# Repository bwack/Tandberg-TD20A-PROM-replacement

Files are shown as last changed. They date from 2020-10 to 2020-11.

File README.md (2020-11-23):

# Tandberg-TD20A-PROM-replacement

A few attempts to solve the problematic, hard to get, hard to program PROM in the Tandberg TD20A Reel to Reel Tape Recorder PROM (U3).

Assembler program written by BWACK 2020.
ROM dumps by Knut Baardsen. RIP. You will always be missed.

Cut pin15 for 15 IPS, ground pin15 for 7.5 IPS

This project was successful. A chip is now installed in a real product that needed repair.
You can see all about it in these two videos:

## Programming

I used the TL866. Load the hex file, set the correct fuses (see the .fuses file).
For myself I have installed minipro on ubuntu, and this is what I run:

minipro -p ATTINY2313 -c code -f ihex -w tda20_prom_attiny2313.hex && \
minipro -p ATTINY2313 -c config -w tda20_prom_attiny2313.fuses

## YouTube videos:

videothumb (http://www.youtube.com/watch?v=v1Pzl6MGUO8 "Creating a PROM replacement using ATTiny2313 and the AVRA Macro Assembler - Tandberg TD20A PROM IC")

TD20 update video showing the chip in action:

videothumb (http://www.youtube.com/watch?v=RYnCFkmXLnY "Tandberg TD 20A update and ATtiny1606 breakout boards (soldering video)")

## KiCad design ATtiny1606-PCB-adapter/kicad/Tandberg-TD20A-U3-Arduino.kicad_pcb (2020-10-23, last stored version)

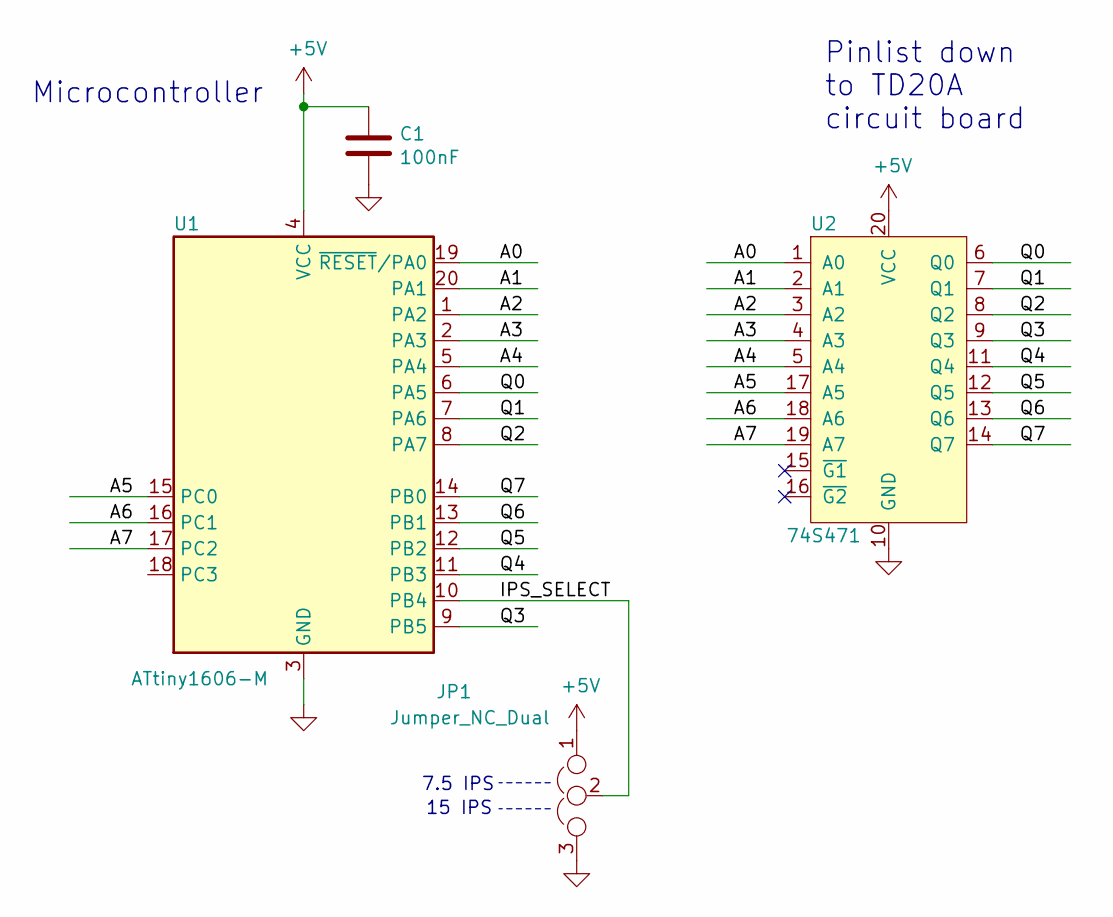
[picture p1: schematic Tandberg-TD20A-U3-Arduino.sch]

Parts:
C1: 100nF; C_0603_1608Metric_Pad1.05x0.95mm_HandSolder
JP1: Jumper_NC_Dual; SolderJumper-3_P1.3mm_Open_RoundedPad1.0x1.5mm_NumberLabels
U1: ATtiny1606-M; VQFN-20-1EP_3x3mm_P0.4mm_EP1.7x1.7mm
U2: 74S471; DIP-20_W7.62mm

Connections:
+5V: C1.1, JP1.1, U1.4 (VCC), U2.20 (VCC)
/A0: U1.19 (~RESET~/PA0), U2.1 (A0)
/A1: U1.20 (PA1), U2.2 (A1)
/A2: U1.1 (PA2), U2.3 (A2)
/A3: U1.2 (PA3), U2.4 (A3)
/A4: U1.5 (PA4), U2.5 (A4)
/A5: U1.15 (PC0), U2.17 (A5)
/A6: U1.16 (PC1), U2.18 (A6)
/A7: U1.17 (PC2), U2.19 (A7)
/IPS_SELECT: JP1.2, U1.10 (PB4)
/Q0: U1.6 (PA5), U2.6 (Q0)
/Q1: U1.7 (PA6), U2.7 (Q1)
/Q2: U1.8 (PA7), U2.8 (Q2)
/Q3: U1.9 (PB5), U2.9 (Q3)
/Q4: U1.11 (PB3), U2.11 (Q4)
/Q5: U1.12 (PB2), U2.12 (Q5)
/Q6: U1.13 (PB1), U2.13 (Q6)
/Q7: U1.14 (PB0), U2.14 (Q7)
GND: C1.2, JP1.3, U1.3 (GND), U1.21 (GND), U2.10 (GND)

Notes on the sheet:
7.5 IPS
15 IPS
Microcontroller
Pinlist down to TD20A circuit board

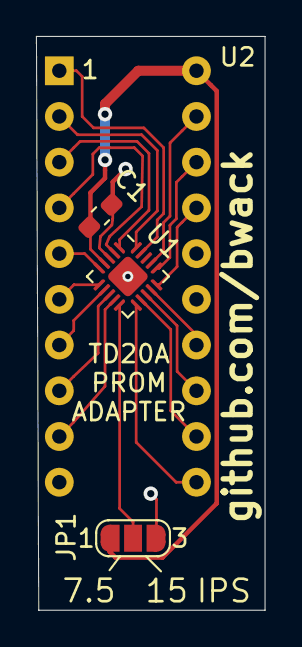
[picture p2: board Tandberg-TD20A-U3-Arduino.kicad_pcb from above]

Board: 2 copper layers, 12.7 x 31.9 mm, 4 parts (0 on the bottom side), 19 nets.

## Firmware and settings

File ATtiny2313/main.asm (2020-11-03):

; Tandberg TD20A Reel to Reel Tape Recorder PROM (U3) drop-in replacement.
; Written by BWACK 2020
; ROM dumps by Knut Baardsen. RIP. You will always be missed.
;
; Cut pin15 for 15 IPS, ground pin15 for 7.5 IPS

.nolist
.ifdef ATTINY2313
.include "tn2313def.inc"
.else
.include "tn2313Adef.inc"
.endif
.list

; inputs
.equ A0		= PA2
.equ A1		= PD0
.equ A2		= PD1
.equ A3		= PA1
.equ A4		= PA0
.equ A5		= PB5
.equ A6		= PB6
.equ A7		= PB7

; outputs
.equ Q0		= PD2
.equ Q1		= PD3
.equ Q2		= PD4
.equ Q3		= PD5
.equ Q4		= PD6
.equ Q5		= PB0
.equ Q6		= PB1
.equ Q7		= PB2

.equ G1_N	= PB3
.equ G2_N	= PB4

.def tmp	= r16
.def tmp2	= r17
.def output     = r18
.def input      = r19

.def loopCt	= r20		; delay loop count
.def loopCt2	= r21		; adc loop count
.def iLoopRl	= r24		; inner loop register low
.def iLoopRh	= r25		; inner loop register high

.dseg
.org	SRAM_START
sample:
.byte	2

.cseg
.org	0x0000		; reset vector
	rjmp setup
.org	WDTaddr		; Watchdog time-out vector
; 	rjmp WDT_isr

.org 0x0013

prom_data_7_5_ips:
.include "prom_data_td20_7.5ips.inc"

prom_data_15_ips:
.include "prom_data_td20_15ips.inc"

setup:
 	ldi	tmp, low(RAMEND)	; init stack pointer
 	out	SPL, tmp
 	; ldi	tmp, high(RAMEND)
 	; out	SPH, tmp

	; inputs
	cbi	DDRA, PA2
	cbi	DDRD, PD0
	cbi	DDRD, PD1
	cbi	DDRA, PA1
	cbi	DDRA, PA0
	cbi	DDRB, PB5
	cbi	DDRB, PB6
	cbi	DDRB, PB7
	cbi	DDRB, G1_N
	cbi	DDRB, G2_N
	sbi	PORTB, G1_N ; pull_up
	sbi	PORTB, G2_N ; pull_up

	; outputs;
	sbi	DDRD, PD2
	sbi	DDRD, PD3
	sbi	DDRD, PD4
	sbi	DDRD, PD5
	sbi	DDRD, PD6
	sbi	DDRB, PB0
	sbi	DDRB, PB1
	sbi	DDRB, PB2


loop:
	; read inputs

	; A4   : PA0
	; A3   : PA1
	; A0   : PA2
	; A1-A2: PD0-PD1
	; A5-A7: PB5-PB7

	clr	input
	in	tmp, PINA
	sbrc	tmp, A4
	ori	input, 0b00010000
	sbrc	tmp, A3
	ori	input, 0b00001000
	sbrc	tmp, A0
	ori	input, 0b00000001

	in	tmp, PINB
	bst	tmp, G1_N
	andi	tmp, 0b11100000
	or	input, tmp

	in	tmp, PIND
	rol	tmp
	andi	tmp, 0b00000110
	or	input, tmp

	; code memory lookup

	brts	td20_prom_15_ips_lookup ; G1_N clear -> 15 IPS
td20_prom_7_5_ips_lookup:
	ldi	ZL, LOW(prom_data_7_5_ips*2)
 	ldi	ZH, HIGH(prom_data_7_5_ips*2)
	rjmp	add_table_offset
td20_prom_15_ips_lookup:
	ldi	ZL, LOW(prom_data_15_ips*2)
 	ldi	ZH, HIGH(prom_data_15_ips*2)
add_table_offset:
 	clr	tmp
 	clc
 	add	ZL, input	; table offset
 	adc	ZH, tmp
 	lpm	output, Z	; lookup

	; set outputs

	; Q0-Q4 = PD2..PD6
	; Q5-Q7 = PB0..PB2

	mov	tmp, output
	andi	tmp, 0x1f
	lsl	tmp	
	lsl	tmp	
	out	PORTD, tmp

	mov	tmp, output
	andi	tmp, 0xe0
	lsr	tmp
	swap	tmp
	ori	tmp, (1<<G1_N)|(1<<G2_N) ; maintain pull-ups
	out	PORTB, tmp

 	; ldi	iloopRl, LOW(100)
 	; ldi	iloopRh, HIGH(100)
 	; rcall	delay_ms
	; ldi	tmp, 1
	; add	output, tmp

	rjmp loop

delay_ms:
.equ delayconst = 80
.equ delayconst2 = 2
	push 	tmp
	push 	tmp2
	ldi	tmp, delayconst
	ldi	tmp2, delayconst2
_delay_ms:
	dec	tmp
	brne	_delay_ms
	ldi	tmp, delayconst
	dec	tmp2
	brne	_delay_ms
	ldi	tmp2, delayconst2

 	sbiw	iloopRl,1
	brne	_delay_ms
	pop	tmp2
	pop	tmp
	ret

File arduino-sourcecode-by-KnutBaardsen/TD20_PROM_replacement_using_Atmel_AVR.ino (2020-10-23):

// Replacement for the TD20A PROM. 
// Circuit in use is an Atmel AVR Mega328, but can be adapted for any MCU with 16 free I/O lines.
// Written by Knut Baardsen September 2016 (knut@baso.no)
// Can be freely used and changed, but not for commercial usage!

byte data_in;
byte data_out;

// Data for 7.5 IPS (PINK color marking)
byte td20_75[256] = {
  0b10000110,0b10000110,0b10100110,0b11000101,0b10100110,0b10100010,0b10100001,0b11100001,
  0b10101110,0b10101010,0b10101001,0b11101001,0b10110110,0b10110010,0b10110001,0b11110001,
  0b11100101,0b10100101,0b11100110,0b10101101,0b10100111,0b10100001,0b10100001,0b10100001,
  0b10100111,0b10100001,0b10100001,0b10100001,0b10111111,0b10100101,0b10100101,0b10101101,
  0b10011110,0b11011111,0b10011110,0b11000101,0b10100110,0b11100011,0b10100001,0b11100001,
  0b10101110,0b11101011,0b10101001,0b11101001,0b10110110,0b11110011,0b10110001,0b11110001,
  0b11101101,0b10101101,0b01101111,0b10101110,0b10100111,0b10100001,0b10100001,0b10100001,
  0b10100111,0b10100001,0b10100001,0b10100001,0b11100110,0b10100101,0b11100110,0b10101101,
  0b10000110,0b10000110,0b10100110,0b11000101,0b10100110,0b10100010,0b10100001,0b11100001,
  0b10101110,0b10101010,0b10101001,0b11101001,0b10110110,0b10110010,0b10110001,0b11110001,
  0b11100101,0b10100101,0b11100110,0b10101101,0b10100111,0b10100001,0b10100001,0b10100001,
  0b10100111,0b10100001,0b10100001,0b10100001,0b10111111,0b10100101,0b10100101,0b10101101,
  0b10011110,0b11011111,0b10011110,0b11000101,0b10100110,0b11100011,0b10100001,0b11100001,
  0b10101110,0b11101011,0b10101001,0b11101001,0b10110110,0b11110011,0b10110001,0b11110001,
  0b11101101,0b10101101,0b01101111,0b10101110,0b10100111,0b10100001,0b10100001,0b10100001,
  0b10100111,0b10100001,0b10100001,0b10100001,0b11100110,0b10100101,0b11100110,0b10101101,
  0b10011110,0b10011110,0b10111110,0b11011101,0b10100010,0b10100010,0b10100001,0b11100001,
  0b10101010,0b10101010,0b10101001,0b11101001,0b10110010,0b10110010,0b10110001,0b11110001,
  0b11100101,0b10100101,0b11100110,0b10101101,0b10100011,0b10100001,0b10100001,0b10100001,
  0b10100011,0b10100001,0b10100001,0b10100001,0b10111111,0b10110101,0b10100101,0b10101101,
  0b10011110,0b11011111,0b10011101,0b11011101,0b10100010,0b11100011,0b10100001,0b11100001,
  0b10101010,0b11101011,0b10101001,0b11101001,0b10110010,0b11110011,0b10110001,0b11110001,
  0b11100101,0b10101101,0b01101111,0b10101110,0b10100011,0b10100001,0b10100001,0b10100001,
  0b10100011,0b10100001,0b10100001,0b10100001,0b11100110,0b10110101,0b11100110,0b10101101,
  0b10011110,0b10011110,0b10111110,0b11011101,0b10100010,0b10100010,0b10100001,0b11100001,
  0b10101010,0b10101010,0b10101001,0b11101001,0b10110010,0b10110010,0b10110001,0b11110001,
  0b11100101,0b10100101,0b11100110,0b10101101,0b10100011,0b10100001,0b10100001,0b10100001,
  0b10100011,0b10100001,0b10100001,0b10100001,0b10111111,0b10110101,0b10100101,0b10101101,
  0b10011110,0b11011111,0b10011101,0b11011101,0b10100010,0b11100011,0b10100001,0b11100001,
  0b10101010,0b11101011,0b10101001,0b11101001,0b10110010,0b11110011,0b10110001,0b11110001,
  0b11100101,0b10101101,0b01101111,0b10101110,0b10100011,0b10100001,0b10100001,0b10100001,
  0b10100011,0b10100001,0b10100001,0b10100001,0b11100110,0b10110101,0b11100110,0b10101101 
};

// Data for 15 IPS (ORANGE color marking)
byte td20_15[256] = {
  0b10000110,0b10000110,0b10100110,0b11000101,0b10100110,0b10100010,0b10100001,0b11100001,
  0b10101110,0b10101010,0b10101001,0b11101001,0b10110110,0b10110010,0b10110001,0b11110001,
  0b11100101,0b10100101,0b11100110,0b10101101,0b10100111,0b10100001,0b10100001,0b10100001,
  0b10100111,0b10100001,0b10100001,0b10100001,0b10111111,0b10100101,0b10100101,0b10101101,
  0b10011110,0b11011111,0b10011110,0b11000101,0b10100110,0b11100011,0b10100001,0b11100001,
  0b10101110,0b11101011,0b10101001,0b11101001,0b10110110,0b11110011,0b10110001,0b11110001,
  0b11101101,0b10101101,0b01101111,0b10101110,0b10100111,0b10100001,0b10100001,0b10100001,
  0b10100111,0b10100001,0b10100001,0b10100001,0b11100110,0b10100101,0b11100110,0b10101101,
  0b10000110,0b10000110,0b10100110,0b11000101,0b10100110,0b10100010,0b10100001,0b11100001,
  0b10101110,0b10101010,0b10101001,0b11101001,0b10110110,0b10110010,0b10110001,0b11110001,
  0b11100101,0b10100101,0b11100110,0b10101101,0b10100111,0b10100001,0b10100001,0b10100001,
  0b10100111,0b10100001,0b10100001,0b10100001,0b10111111,0b10100101,0b10100101,0b10101101,
  0b10011110,0b11011111,0b10011110,0b11000101,0b10100110,0b11100011,0b10100001,0b11100001,
  0b10101110,0b11101011,0b10101001,0b11101001,0b10110110,0b11110011,0b10110001,0b11110001,
  0b11101101,0b10101101,0b01101111,0b10101110,0b10100111,0b10100001,0b10100001,0b10100001,
  0b10100111,0b10100001,0b10100001,0b10100001,0b11100110,0b10100101,0b11100110,0b10101101,
  0b10011110,0b10011110,0b10111110,0b11011101,0b10100010,0b10100010,0b10100001,0b11100001,
  0b10101010,0b10101010,0b10101001,0b11101001,0b10110010,0b10110010,0b10110001,0b11110001,
  0b11100101,0b10100101,0b11100110,0b10101101,0b10100011,0b10100001,0b10100001,0b10100001,
  0b10100011,0b10100001,0b10100001,0b10100001,0b10111111,0b10110101,0b10100101,0b10101101,
  0b10011110,0b11011111,0b10011101,0b11011101,0b10100010,0b11100011,0b10100001,0b11100001,
  0b10101010,0b11101011,0b10101001,0b11101001,0b10110010,0b11110011,0b10110001,0b11110001,
  0b11100101,0b10101101,0b01101111,0b10101110,0b10100011,0b10100001,0b10100001,0b10100001,
  0b10100011,0b10100001,0b10100001,0b10100001,0b11100110,0b10110101,0b11100110,0b10101101,
  0b10011010,0b10011010,0b10111010,0b11011001,0b10100010,0b10100010,0b10100001,0b11100001,
  0b10101010,0b10101010,0b10101001,0b11101001,0b10110010,0b10110010,0b10110001,0b11110001,
  0b11111001,0b10111001,0b11111010,0b10111001,0b10100011,0b10100001,0b10100001,0b10100001,
  0b10100011,0b10100001,0b10100001,0b10100001,0b10111011,0b10110101,0b10100101,0b10101101,
  0b10011010,0b11011011,0b10011010,0b11011001,0b10100010,0b11100011,0b10100001,0b11100001,
  0b10101010,0b11101011,0b10101001,0b11101001,0b10110010,0b11110011,0b10110001,0b11110001,
  0b11101001,0b10111001,0b01101111,0b10111010,0b10100011,0b10100001,0b10100001,0b10100001,
  0b10100011,0b10100001,0b10100001,0b10100001,0b11100110,0b10110101,0b11100110,0b10101101 
};


void setup() {
  // Input is built up as (D7,D6,D5,D4,D3,D2,B1,B0) (MSB,LSB)
  // Output is built up as (C3,C2,C1,C0,B5,B4,B3,B2) (MSB,LSB)
  DDRB = 0x7C;
  DDRC = 0x0F;
}


void loop() {
  // Read input 
  data_in  = (PIND & 0xFC) | (PINB & 0x03);
  
  // Get TD20 data for 7.5 IPS or for the TD20AL (logging)
  data_out = td20_75[data_in];
  // Get TD20 data for 15 IPS
  // data_out = td20_15[data_in];
  // NB! Remember to comment out the one not used!
  
  // Write output
  PORTB = (data_out << 2) & 0x7C;
  PORTC = ((data_out & 0xF0) >> 4) & 0x0F;   
}

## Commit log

2020-10-26 Fixed a major bug. Double pipe in ()|() statement.
    [main.asm]
2020-11-02 removed the adapter from this project. changed readme
    [Tandberg-TD20A-U3-Arduino-B_Cu.gbr, Tandberg-TD20A-U3-Arduino-B_Mask.gbr, Tandberg-TD20A-U3-Arduino-B_Paste.gbr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]
2020-11-05 update readme. added fuse-file for ATTINY2313A
